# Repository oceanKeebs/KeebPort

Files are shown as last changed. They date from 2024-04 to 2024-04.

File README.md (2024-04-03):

# KeebPort

Keeb Port is a split keyboard architecture with a central part housing a micro controller and 6 keys (two keys can be replaced with encoders optionally). Right and left part of the split keyboard do not include a micro controller but an IO expander (MCP23017) processing the key activation information and connected via i2c to the central part. The LED control signal is generated by the micro controller and provided via a separate line to both split keyboard parts. Central and split keyboard parts are connected with TRRRS (5-pin). All layouts share the same firmware.

## QMK Firmware source files

### RP2040 QMK firmware source files

<https://github.com/oceanKeebs/qmk_firmware/tree/master/keyboards/oceankeebs/expanded_split_rp_tps43>

## QMK Firmware hex files

### RP2040 QMK firmware hex files

**without via support:**
<https://github.com/oceanKeebs/KeebPort/blob/main/HexFiles/oceankeebs_expanded_split_rp_tps43_default.uf2>

**with via support:**
<https://github.com/oceanKeebs/KeebPort/blob/main/HexFiles/oceankeebs_expanded_split_rp_tps43_via.uf2>

## Keeb Port RP2040

Central part for all split keyboard layouts housing a PGA2040, a TPS65 touch pad and 6 keys (two keys can be replaced with encoders optionally). Needed for all keyboard layouts of this repository.
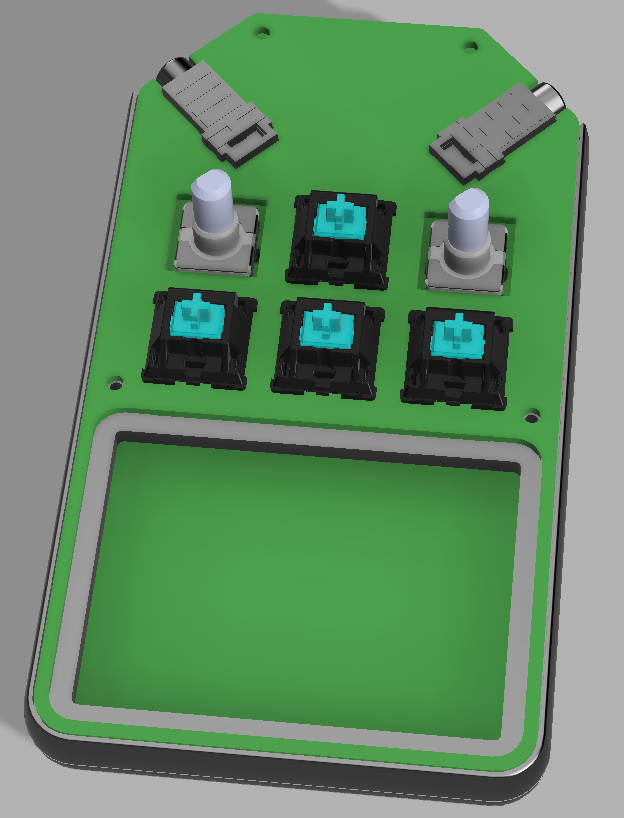
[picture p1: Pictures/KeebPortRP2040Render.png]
KeebPortRP2040Render


### PCBs

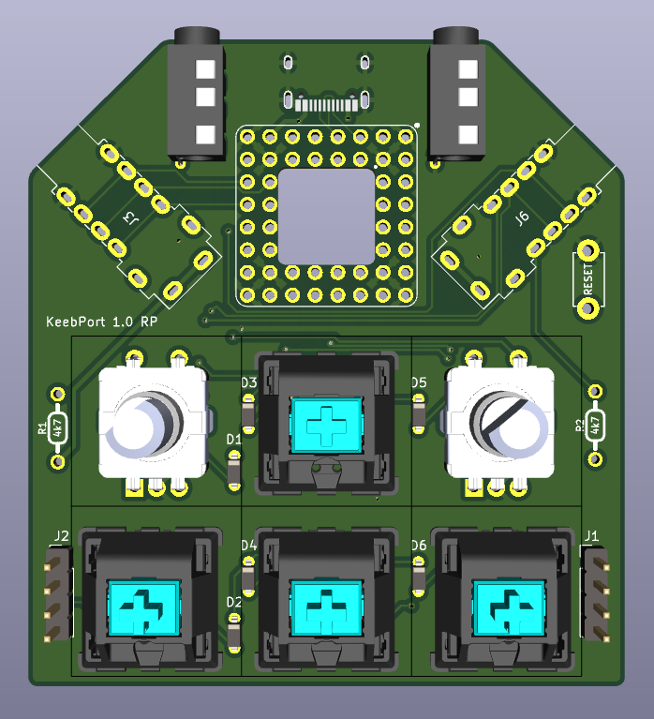
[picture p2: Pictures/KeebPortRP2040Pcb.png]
Keeb Port Pcb

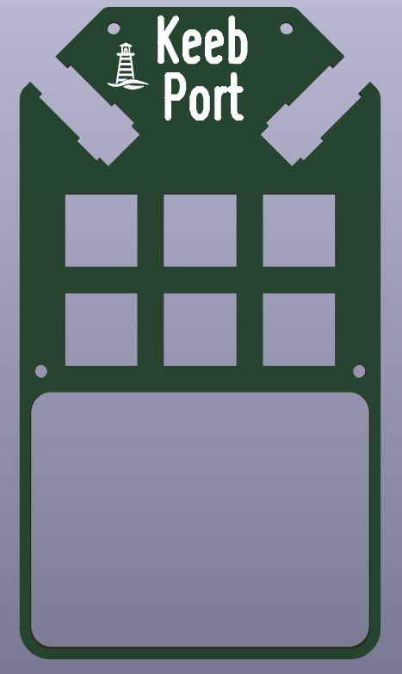
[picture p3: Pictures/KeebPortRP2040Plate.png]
Keeb Port Plate

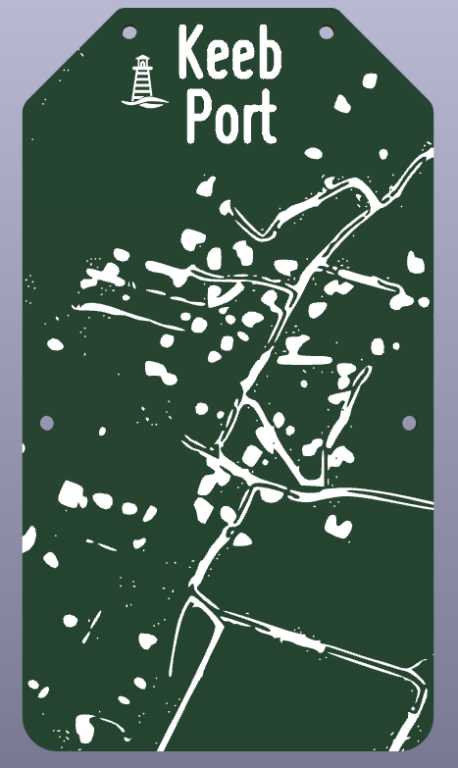
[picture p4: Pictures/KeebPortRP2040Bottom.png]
Keeb Port Bottom


### STLs

<https://github.com/oceanKeebs/KeebPort/StlFiles/KeebPort_RP2040>

## Kyrious Crab

A SplitKb Kyria inspired split keyboard layout with more aggressive stagger and added num row. Per side 31 keys are available.
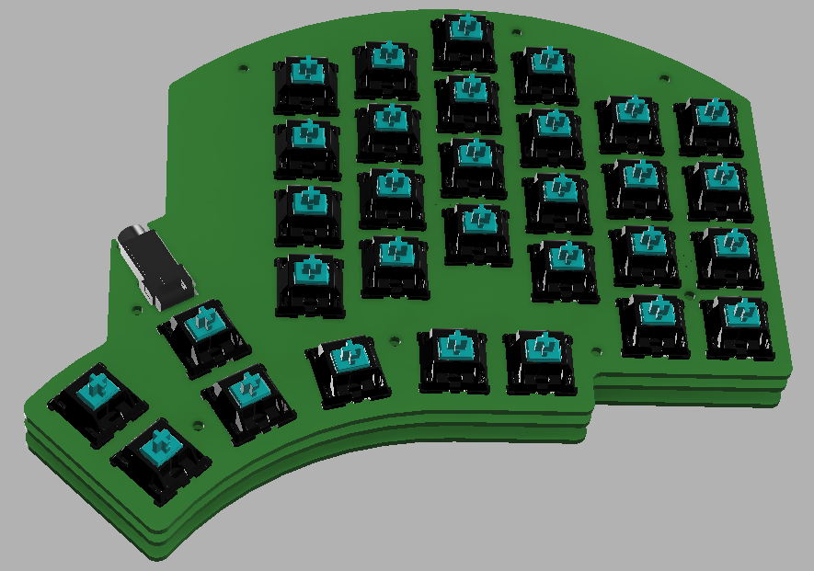
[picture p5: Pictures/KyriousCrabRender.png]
KyriousCrabRender


### PCBs

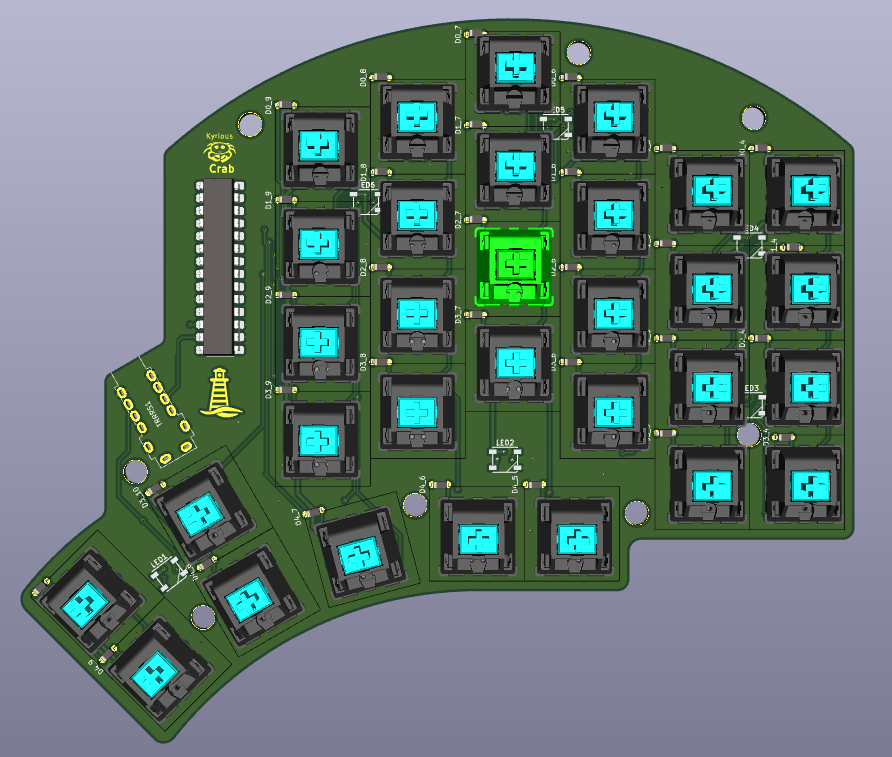
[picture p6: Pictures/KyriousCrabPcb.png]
Kyrious Crab Pcb

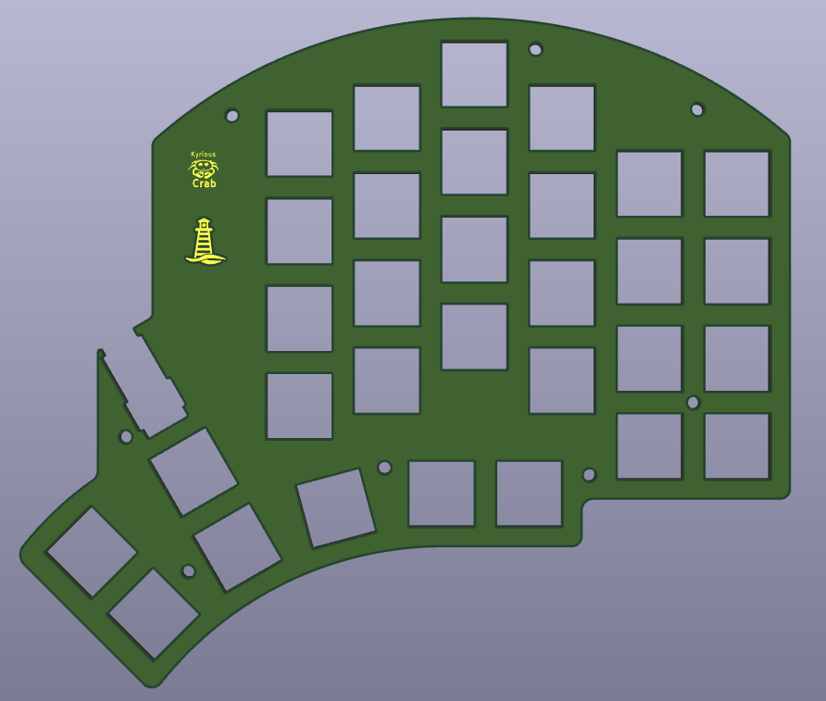
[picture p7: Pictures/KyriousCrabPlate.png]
Kyrious Crab Plate

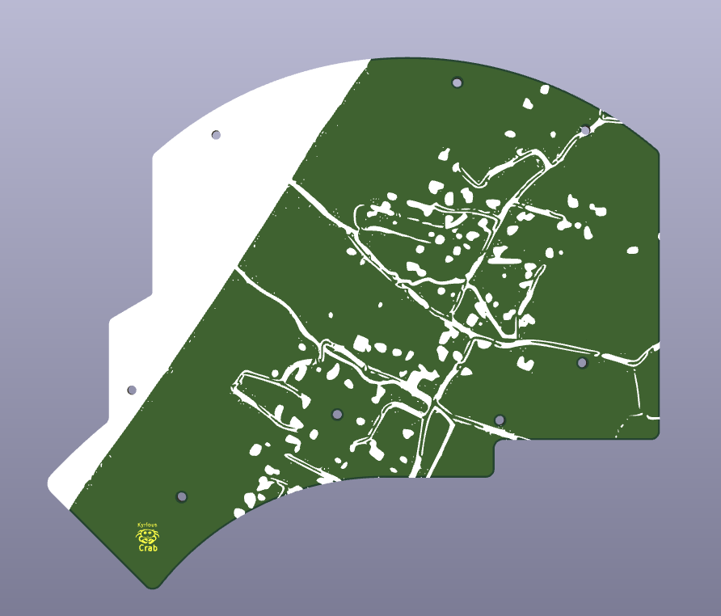
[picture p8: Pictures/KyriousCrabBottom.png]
Kyrious Crab Bottom


## Lucky Albatros

A Lily58 inspired split keyboard layout with 3 additional columns for arrow keys and/or macros. Per side 33 keys are available.
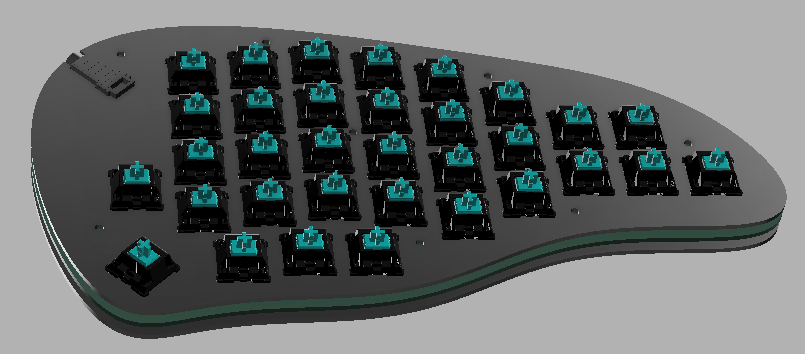
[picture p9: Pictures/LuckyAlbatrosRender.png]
LuckyAlbatrosRender


### PCBs

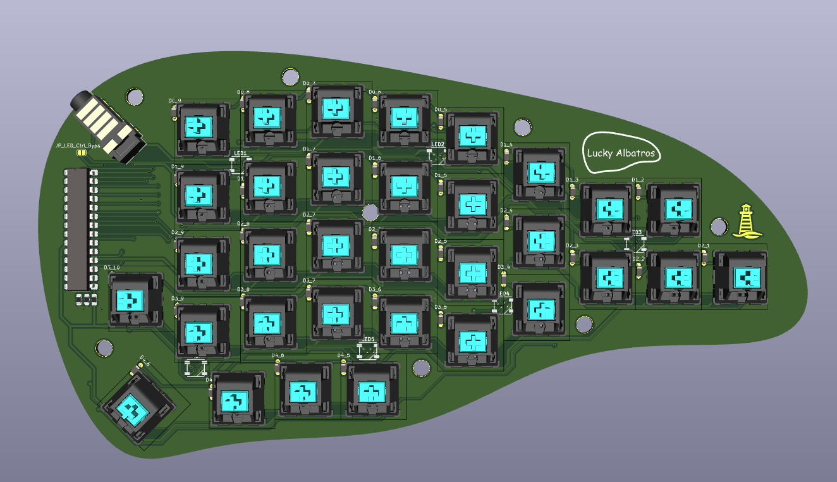
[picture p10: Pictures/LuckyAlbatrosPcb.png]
Lucky Albatros Pcb

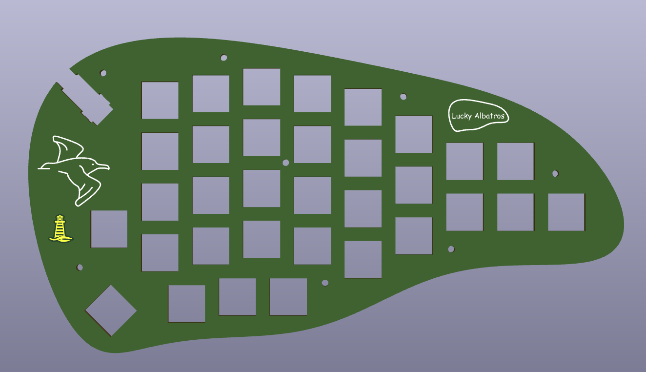
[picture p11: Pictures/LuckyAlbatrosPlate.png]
Lucky Albatros Plate

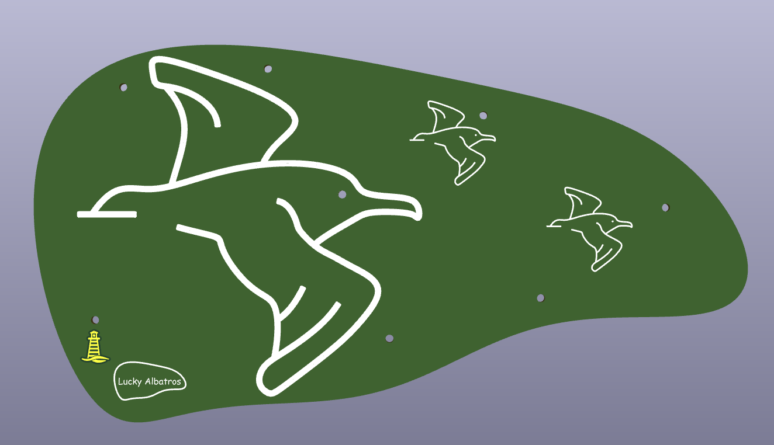
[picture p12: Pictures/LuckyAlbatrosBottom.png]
Lucky Albatros Bottom


## Template for Custom Layouts

The template can be used a starting point to design compatible custom layouts.

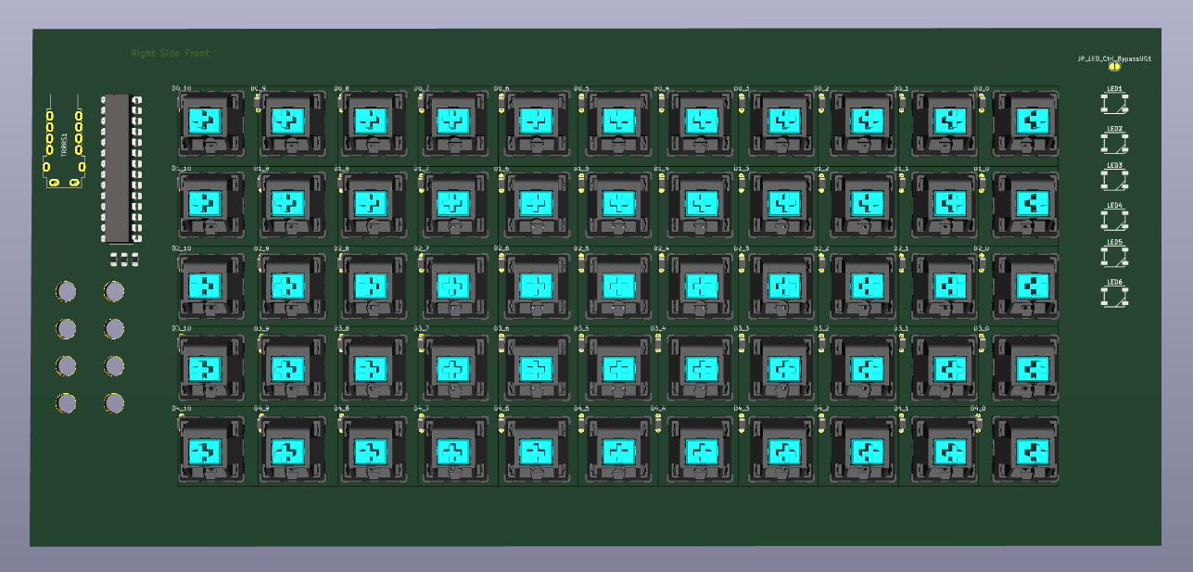
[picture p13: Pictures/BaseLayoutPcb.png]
Base Split Template


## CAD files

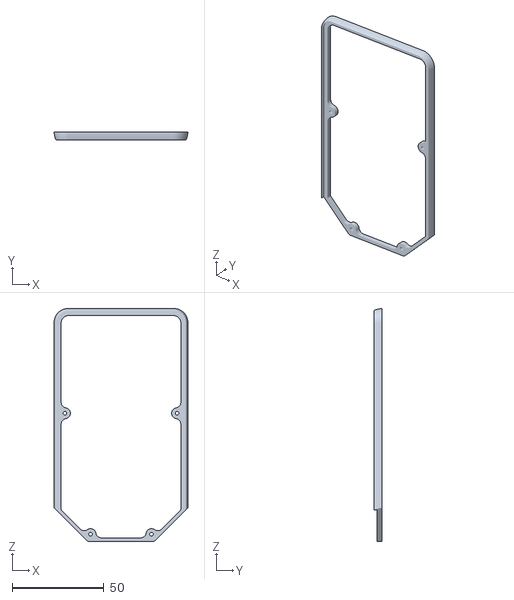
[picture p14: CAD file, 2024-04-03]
StlFiles/KeebPort_RP2040/Midplate_bottom.stl
73.0 x 4.20 x 127.0

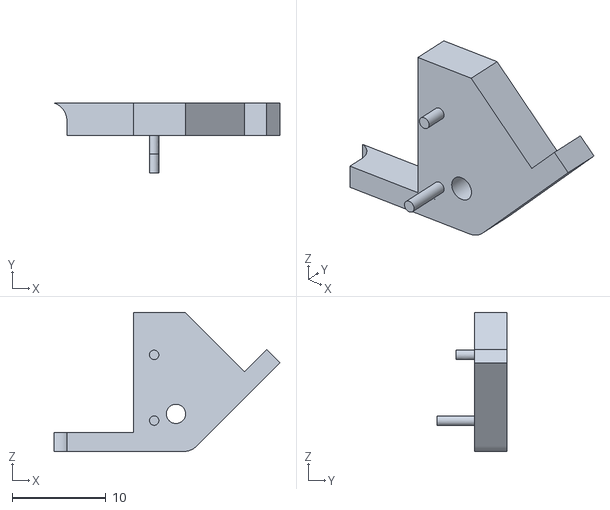
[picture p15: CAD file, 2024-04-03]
StlFiles/KeebPort_RP2040/Midplate_OR.stl
24.1 x 7.45 x 14.8

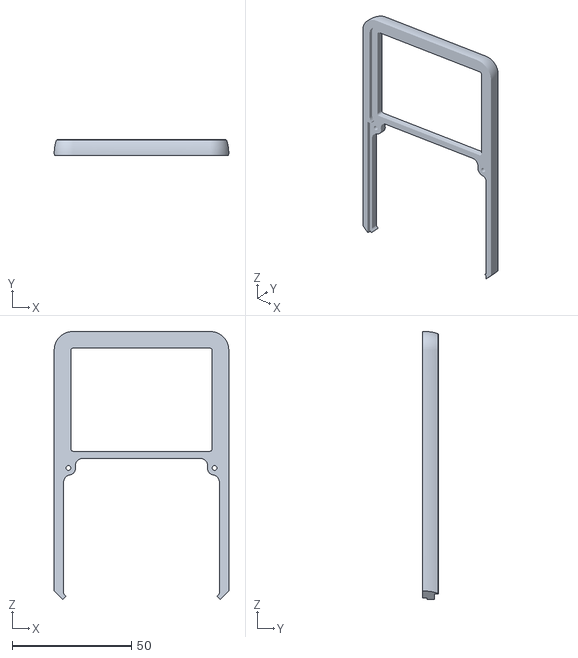
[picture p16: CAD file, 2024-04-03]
StlFiles/KeebPort_RP2040/Midplate_top.stl
73.1 x 6.60 x 112.2

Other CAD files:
StlFiles/KeebPort_RP2040/Midplate_OL.stl

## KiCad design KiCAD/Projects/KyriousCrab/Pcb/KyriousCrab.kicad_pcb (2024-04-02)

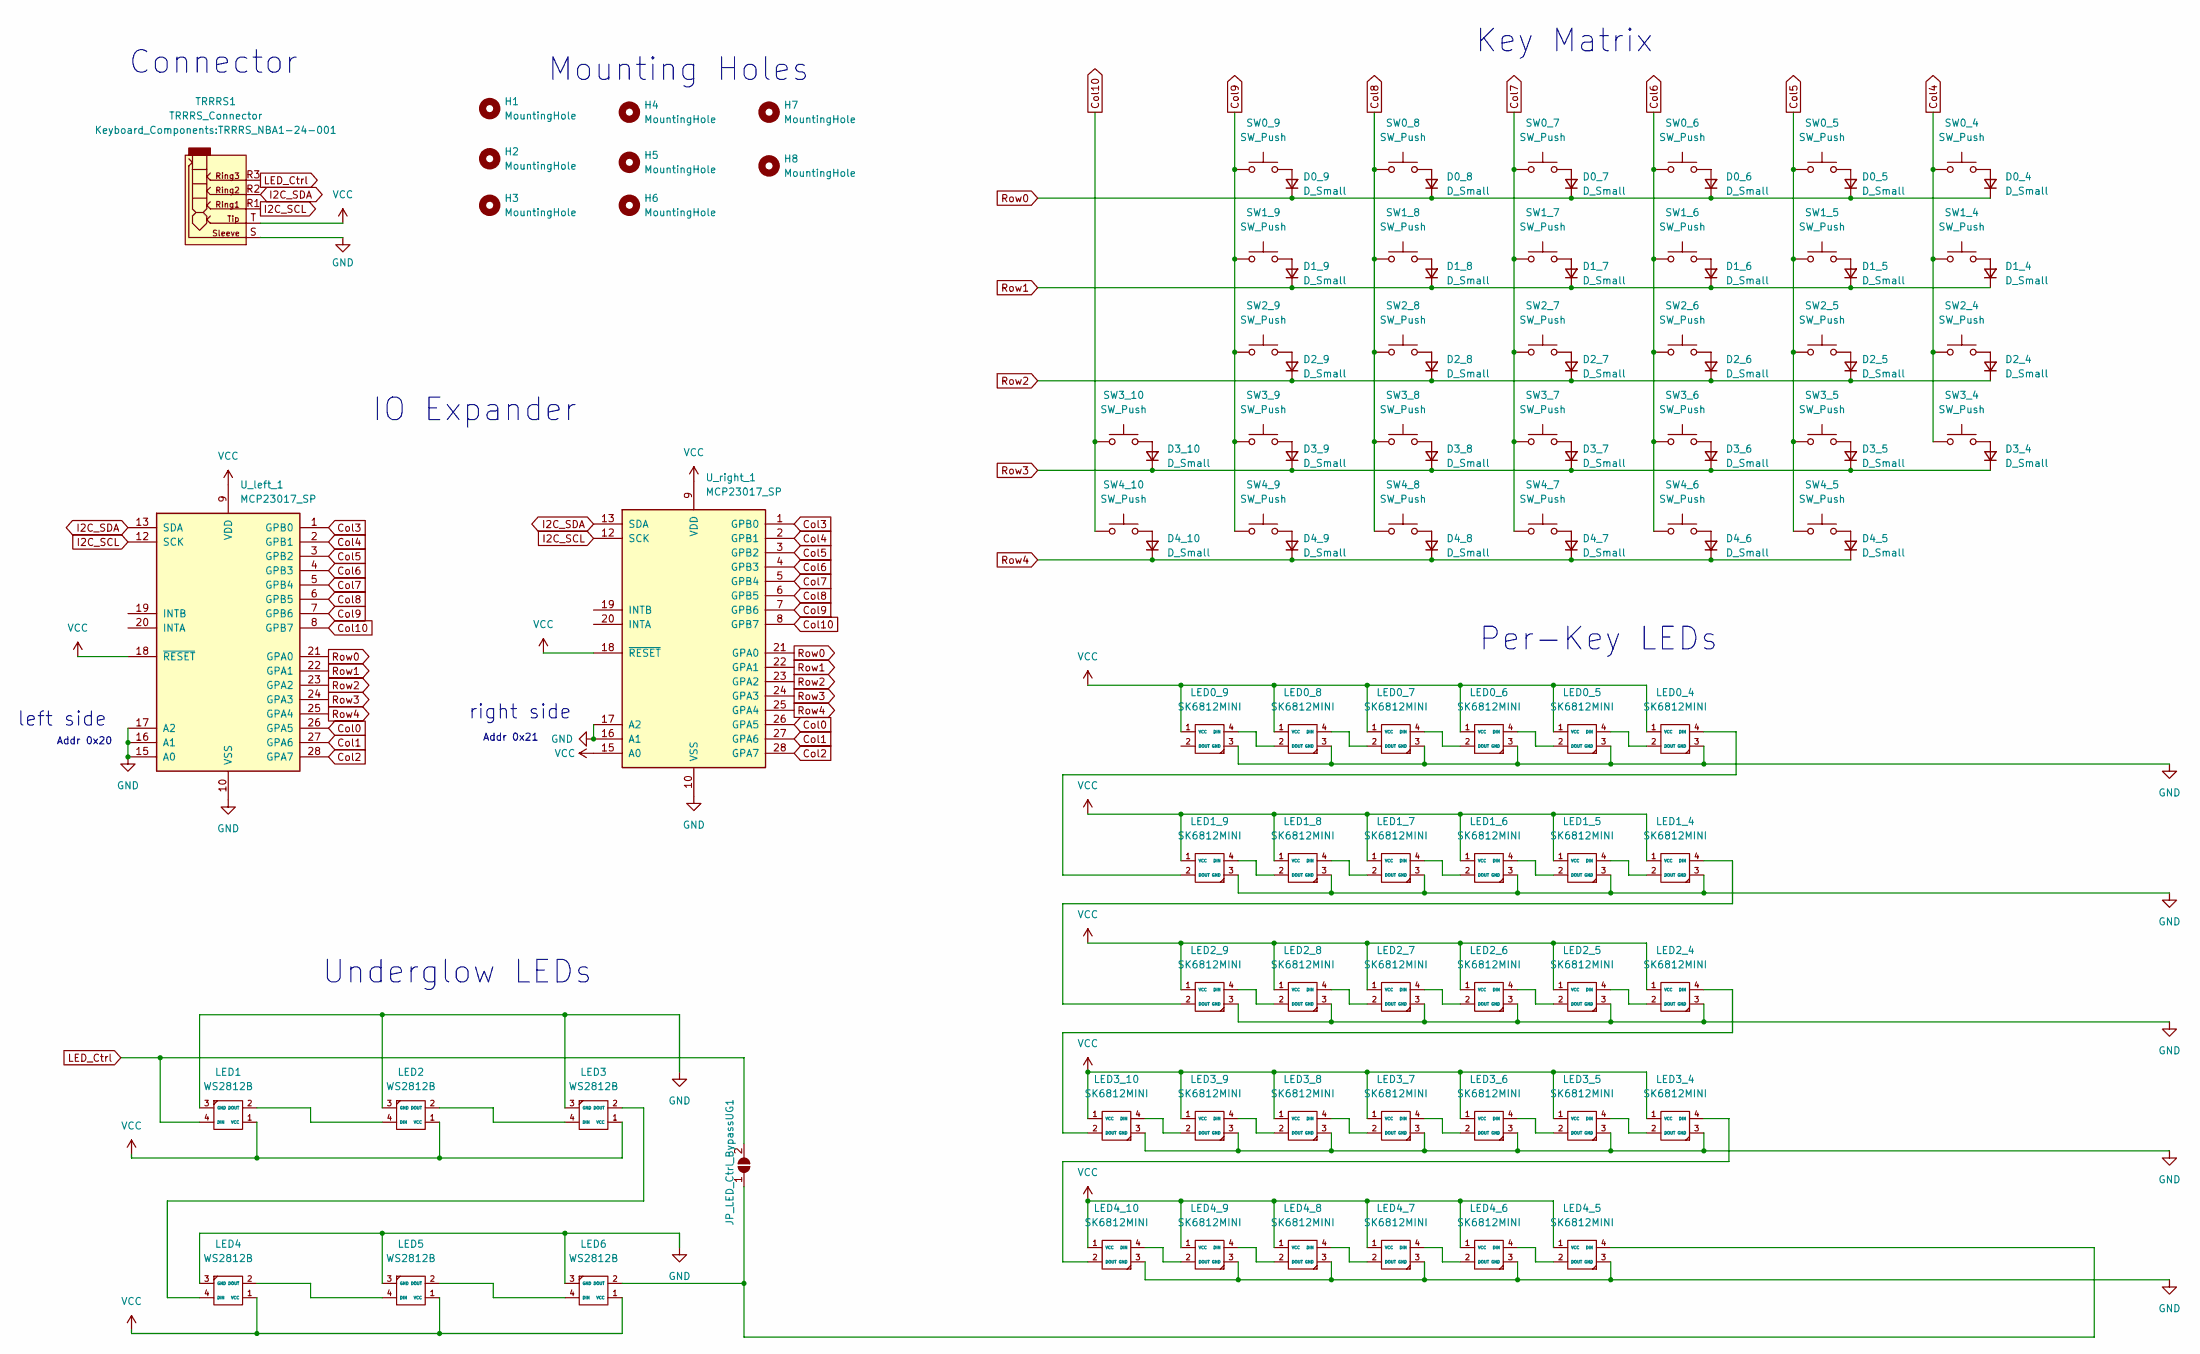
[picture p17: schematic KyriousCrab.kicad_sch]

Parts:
D0_4, D0_5, D0_6, D0_7, D0_8, D0_9, D1_4, D1_5, D1_6, D1_7, D1_8, D1_9, D2_4, D2_5, D2_6, D2_7, D2_8, D2_9, D3_4, D3_5, D3_6, D3_7, D3_8, D3_9, D3_10, D4_5, D4_6, D4_7, D4_8, D4_9, D4_10: D_Small; Diode_SMD_Round_Pads
H1, H2, H3, H4, H5, H6, H7, H8: MountingHole; Throughhole_Standoff
JP_LED_Ctrl_BypassUG1: SolderJumper_2_Open; SolderJumper-2_P1.3mm_Open_RoundedPad1.0x1.5mm
LED0_4, LED0_5, LED0_6, LED0_7, LED0_8, LED0_9, LED1_4, LED1_5, LED1_6, LED1_7, LED1_8, LED1_9, LED2_4, LED2_5, LED2_6, LED2_7, LED2_8, LED2_9, LED3_4, LED3_5, LED3_6, LED3_7, LED3_8, LED3_9, LED3_10, LED4_5, LED4_6, LED4_7, LED4_8, LED4_9, LED4_10: SK6812MINI; SK6812MiniE_MX_Addon
LED1, LED2, LED3, LED4, LED5, LED6: WS2812B; WS2812B_doublesided
SW0_4, SW0_5, SW0_6, SW0_7, SW0_8, SW0_9, SW1_4, SW1_5, SW1_6, SW1_7, SW1_8, SW1_9, SW2_4, SW2_5, SW2_6, SW2_7, SW2_8, SW2_9, SW3_4, SW3_5, SW3_6, SW3_7, SW3_8, SW3_9, SW3_10, SW4_5, SW4_6, SW4_7, SW4_8, SW4_9, SW4_10: SW_Push; MX_lss_100U_doubleSided
TRRRS1: TRRRS_Connector; TRRRS_NBA1-24-001
U_left_1: MCP23017_SP; MCP23017_THTasSMD_Singlesided
U_right_1: MCP23017_SP; MCP23017_THTasSMD_Singlesided

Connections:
Col0: U_left_1.26 (GPA5), U_right_1.26 (GPA5)
Col1: U_left_1.27 (GPA6), U_right_1.27 (GPA6)
Col2: U_left_1.28 (GPA7), U_right_1.28 (GPA7)
Col3: U_left_1.1 (GPB0), U_right_1.1 (GPB0)
Col4: SW0_4.1, SW1_4.1, SW2_4.1, SW3_4.1, U_left_1.2 (GPB1), U_right_1.2 (GPB1)
Col5: SW0_5.1, SW1_5.1, SW2_5.1, SW3_5.1, SW4_5.1, U_left_1.3 (GPB2), U_right_1.3 (GPB2)
Col6: SW0_6.1, SW1_6.1, SW2_6.1, SW3_6.1, SW4_6.1, U_left_1.4 (GPB3), U_right_1.4 (GPB3)
Col7: SW0_7.1, SW1_7.1, SW2_7.1, SW3_7.1, SW4_7.1, U_left_1.5 (GPB4), U_right_1.5 (GPB4)
Col8: SW0_8.1, SW1_8.1, SW2_8.1, SW3_8.1, SW4_8.1, U_left_1.6 (GPB5), U_right_1.6 (GPB5)
Col9: SW0_9.1, SW1_9.1, SW2_9.1, SW3_9.1, SW4_9.1, U_left_1.7 (GPB6), U_right_1.7 (GPB6)
Col10: SW3_10.1, SW4_10.1, U_left_1.8 (GPB7), U_right_1.8 (GPB7)
GND: LED0_4.3 (GND), LED0_5.3 (GND), LED0_6.3 (GND), LED0_7.3 (GND), LED0_8.3 (GND), LED0_9.3 (GND), LED1.3 (GND), LED1_4.3 (GND), LED1_5.3 (GND), LED1_6.3 (GND), LED1_7.3 (GND), LED1_8.3 (GND), LED1_9.3 (GND), LED2.3 (GND), LED2_4.3 (GND), LED2_5.3 (GND), LED2_6.3 (GND), LED2_7.3 (GND), LED2_8.3 (GND), LED2_9.3 (GND), LED3.3 (GND), LED3_4.3 (GND), LED3_5.3 (GND), LED3_6.3 (GND), LED3_7.3 (GND), LED3_8.3 (GND), LED3_9.3 (GND), LED3_10.3 (GND), LED4.3 (GND), LED4_5.3 (GND), LED4_6.3 (GND), LED4_7.3 (GND), LED4_8.3 (GND), LED4_9.3 (GND), LED4_10.3 (GND), LED5.3 (GND), LED6.3 (GND), TRRRS1.S, U_left_1.10 (VSS), U_left_1.15 (A0), U_left_1.16 (A1), U_left_1.17 (A2), U_right_1.10 (VSS), U_right_1.16 (A1), U_right_1.17 (A2)
I2C_SCL: TRRRS1.R1, U_left_1.12 (SCK), U_right_1.12 (SCK)
I2C_SDA: TRRRS1.R2, U_left_1.13 (SDA), U_right_1.13 (SDA)
LED_Ctrl: JP_LED_Ctrl_BypassUG1.2 (B), LED1.4 (DIN), TRRRS1.R3
unnamed: D0_4.2 (A), SW0_4.2
unnamed: D0_5.2 (A), SW0_5.2
unnamed: D0_6.2 (A), SW0_6.2
unnamed: D0_7.2 (A), SW0_7.2
unnamed: D0_8.2 (A), SW0_8.2
unnamed: D0_9.2 (A), SW0_9.2
unnamed: D1_4.2 (A), SW1_4.2
unnamed: D1_5.2 (A), SW1_5.2
unnamed: D1_6.2 (A), SW1_6.2
unnamed: D1_7.2 (A), SW1_7.2
unnamed: D1_8.2 (A), SW1_8.2
unnamed: D1_9.2 (A), SW1_9.2
unnamed: D2_4.2 (A), SW2_4.2
unnamed: D2_5.2 (A), SW2_5.2
unnamed: D2_6.2 (A), SW2_6.2
unnamed: D2_7.2 (A), SW2_7.2
unnamed: D2_8.2 (A), SW2_8.2
unnamed: D2_9.2 (A), SW2_9.2
unnamed: D3_4.2 (A), SW3_4.2
unnamed: D3_5.2 (A), SW3_5.2
unnamed: D3_6.2 (A), SW3_6.2
unnamed: D3_7.2 (A), SW3_7.2
unnamed: D3_8.2 (A), SW3_8.2
unnamed: D3_9.2 (A), SW3_9.2
unnamed: D3_10.2 (A), SW3_10.2
unnamed: D4_5.2 (A), SW4_5.2
unnamed: D4_6.2 (A), SW4_6.2
unnamed: D4_7.2 (A), SW4_7.2
unnamed: D4_8.2 (A), SW4_8.2
unnamed: D4_9.2 (A), SW4_9.2
unnamed: D4_10.2 (A), SW4_10.2
unnamed: JP_LED_Ctrl_BypassUG1.1 (A), LED4_5.4 (DIN), LED6.2 (DOUT)
unnamed: LED0_4.2 (DOUT), LED0_5.4 (DIN)
unnamed: LED0_4.4 (DIN), LED1_9.2 (DOUT)
unnamed: LED0_5.2 (DOUT), LED0_6.4 (DIN)
unnamed: LED0_6.2 (DOUT), LED0_7.4 (DIN)
unnamed: LED0_7.2 (DOUT), LED0_8.4 (DIN)
unnamed: LED0_8.2 (DOUT), LED0_9.4 (DIN)
unnamed: LED1.2 (DOUT), LED2.4 (DIN)
unnamed: LED1_4.2 (DOUT), LED1_5.4 (DIN)
unnamed: LED1_4.4 (DIN), LED2_9.2 (DOUT)
unnamed: LED1_5.2 (DOUT), LED1_6.4 (DIN)
unnamed: LED1_6.2 (DOUT), LED1_7.4 (DIN)
unnamed: LED1_7.2 (DOUT), LED1_8.4 (DIN)
unnamed: LED1_8.2 (DOUT), LED1_9.4 (DIN)
unnamed: LED2.2 (DOUT), LED3.4 (DIN)
unnamed: LED2_4.2 (DOUT), LED2_5.4 (DIN)
unnamed: LED2_4.4 (DIN), LED3_10.2 (DOUT)
unnamed: LED2_5.2 (DOUT), LED2_6.4 (DIN)
unnamed: LED2_6.2 (DOUT), LED2_7.4 (DIN)
unnamed: LED2_7.2 (DOUT), LED2_8.4 (DIN)
unnamed: LED2_8.2 (DOUT), LED2_9.4 (DIN)
unnamed: LED3.2 (DOUT), LED4.4 (DIN)
unnamed: LED3_4.2 (DOUT), LED3_5.4 (DIN)
unnamed: LED3_4.4 (DIN), LED4_10.2 (DOUT)
unnamed: LED3_5.2 (DOUT), LED3_6.4 (DIN)
unnamed: LED3_6.2 (DOUT), LED3_7.4 (DIN)
unnamed: LED3_7.2 (DOUT), LED3_8.4 (DIN)
unnamed: LED3_8.2 (DOUT), LED3_9.4 (DIN)
unnamed: LED3_9.2 (DOUT), LED3_10.4 (DIN)
unnamed: LED4.2 (DOUT), LED5.4 (DIN)
unnamed: LED4_5.2 (DOUT), LED4_6.4 (DIN)
unnamed: LED4_6.2 (DOUT), LED4_7.4 (DIN)
unnamed: LED4_7.2 (DOUT), LED4_8.4 (DIN)
unnamed: LED4_8.2 (DOUT), LED4_9.4 (DIN)
unnamed: LED4_9.2 (DOUT), LED4_10.4 (DIN)
unnamed: LED5.2 (DOUT), LED6.4 (DIN)
Row0: D0_4.1 (K), D0_5.1 (K), D0_6.1 (K), D0_7.1 (K), D0_8.1 (K), D0_9.1 (K), U_left_1.21 (GPA0), U_right_1.21 (GPA0)
Row1: D1_4.1 (K), D1_5.1 (K), D1_6.1 (K), D1_7.1 (K), D1_8.1 (K), D1_9.1 (K), U_left_1.22 (GPA1), U_right_1.22 (GPA1)
Row2: D2_4.1 (K), D2_5.1 (K), D2_6.1 (K), D2_7.1 (K), D2_8.1 (K), D2_9.1 (K), U_left_1.23 (GPA2), U_right_1.23 (GPA2)
Row3: D3_4.1 (K), D3_5.1 (K), D3_6.1 (K), D3_7.1 (K), D3_8.1 (K), D3_9.1 (K), D3_10.1 (K), U_left_1.24 (GPA3), U_right_1.24 (GPA3)
Row4: D4_5.1 (K), D4_6.1 (K), D4_7.1 (K), D4_8.1 (K), D4_9.1 (K), D4_10.1 (K), U_left_1.25 (GPA4), U_right_1.25 (GPA4)
VCC: LED0_4.1 (VCC), LED0_5.1 (VCC), LED0_6.1 (VCC), LED0_7.1 (VCC), LED0_8.1 (VCC), LED0_9.1 (VCC), LED1.1 (VCC), LED1_4.1 (VCC), LED1_5.1 (VCC), LED1_6.1 (VCC), LED1_7.1 (VCC), LED1_8.1 (VCC), LED1_9.1 (VCC), LED2.1 (VCC), LED2_4.1 (VCC), LED2_5.1 (VCC), LED2_6.1 (VCC), LED2_7.1 (VCC), LED2_8.1 (VCC), LED2_9.1 (VCC), LED3.1 (VCC), LED3_4.1 (VCC), LED3_5.1 (VCC), LED3_6.1 (VCC), LED3_7.1 (VCC), LED3_8.1 (VCC), LED3_9.1 (VCC), LED3_10.1 (VCC), LED4.1 (VCC), LED4_5.1 (VCC), LED4_6.1 (VCC), LED4_7.1 (VCC), LED4_8.1 (VCC), LED4_9.1 (VCC), LED4_10.1 (VCC), LED5.1 (VCC), LED6.1 (VCC), TRRRS1.T, U_left_1.9 (VDD), U_left_1.18 (~RESET), U_right_1.9 (VDD), U_right_1.15 (A0), U_right_1.18 (~RESET)

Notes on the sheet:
IO Expander
Mounting Holes
Underglow LEDs
Connector
Addr 0x21
right side
left side
Key Matrix
Per-Key LEDs
Addr 0x20

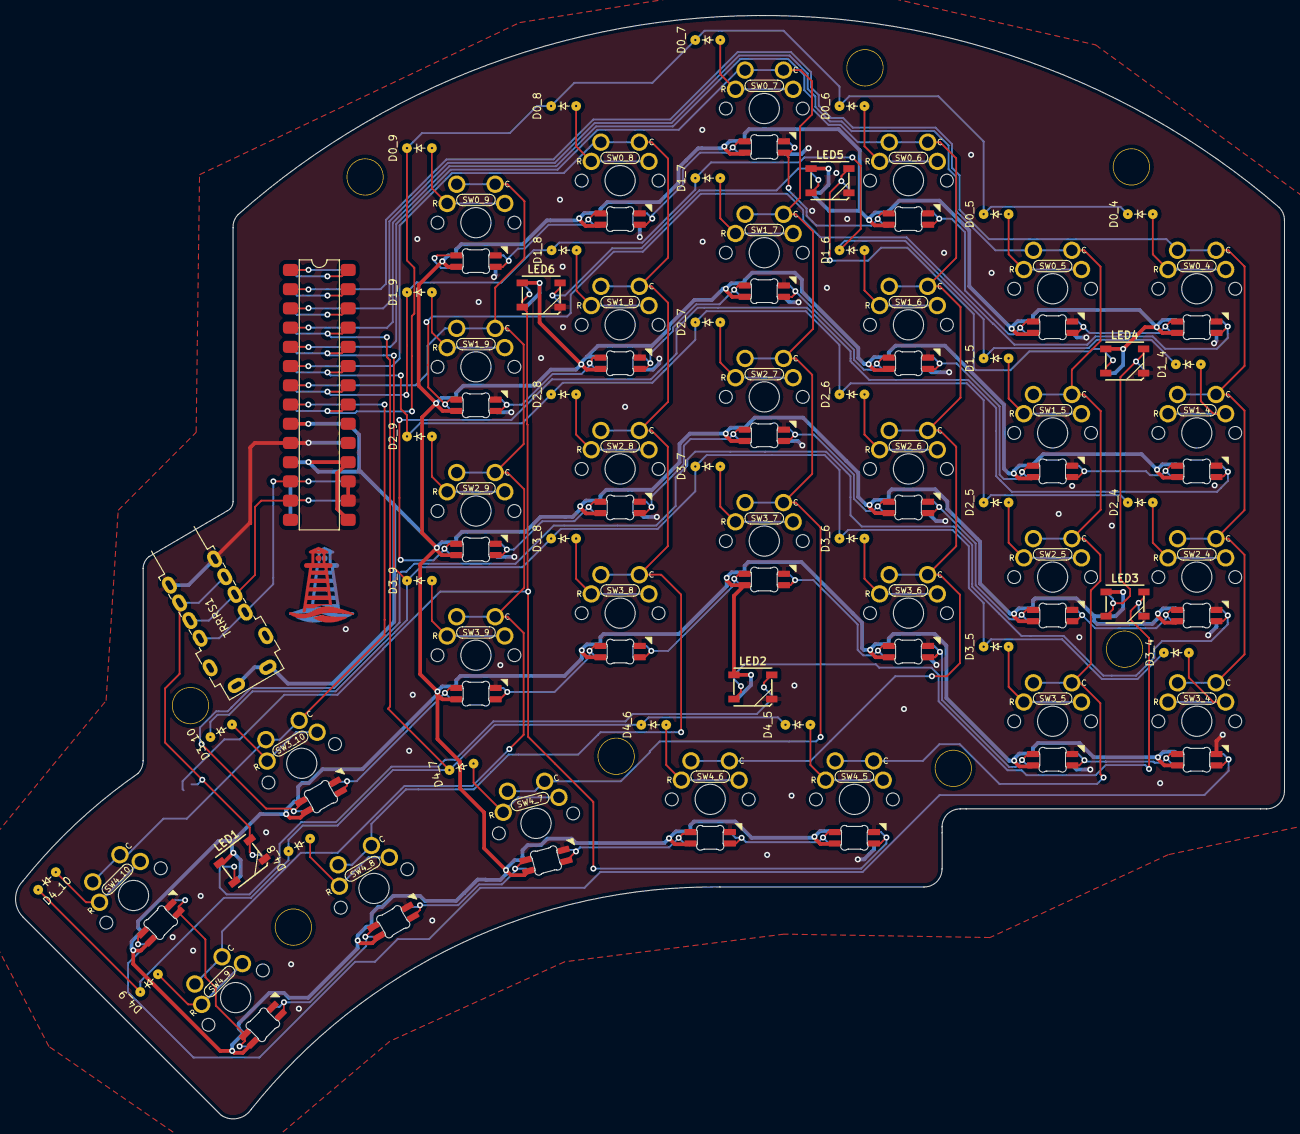
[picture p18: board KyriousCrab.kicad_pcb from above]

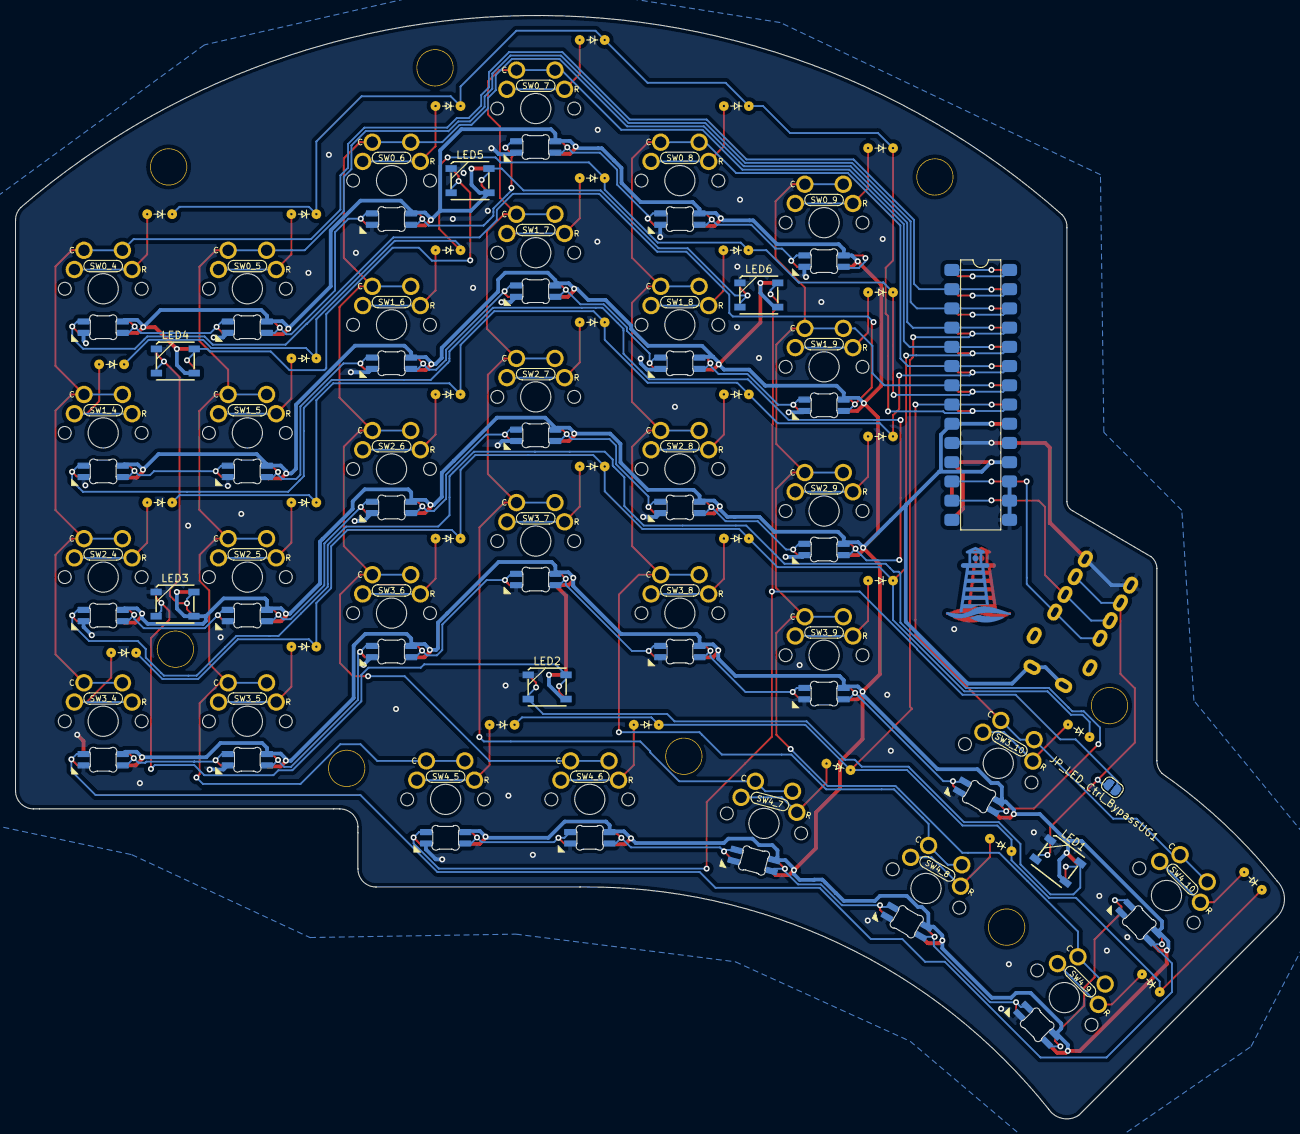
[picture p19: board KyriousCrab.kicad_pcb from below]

Board: 2 copper layers, 167.7 x 145.8 mm, 112 parts (2 on the bottom side), 88 nets.

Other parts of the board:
Ref**: Val**; Leuchtturm_10x10

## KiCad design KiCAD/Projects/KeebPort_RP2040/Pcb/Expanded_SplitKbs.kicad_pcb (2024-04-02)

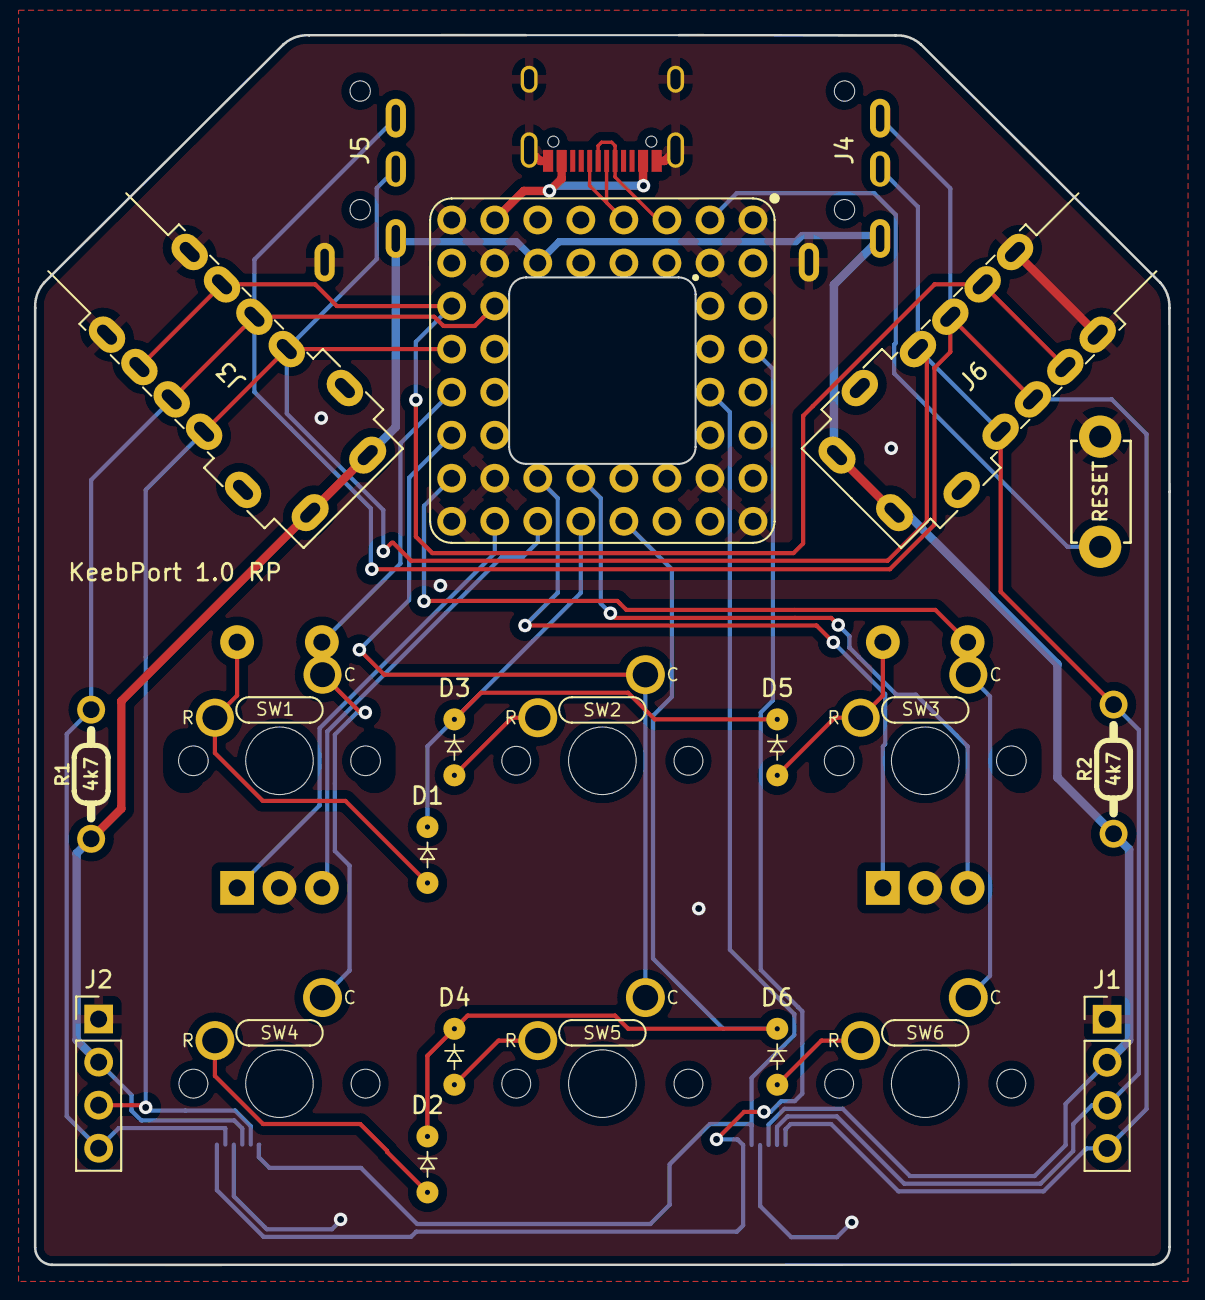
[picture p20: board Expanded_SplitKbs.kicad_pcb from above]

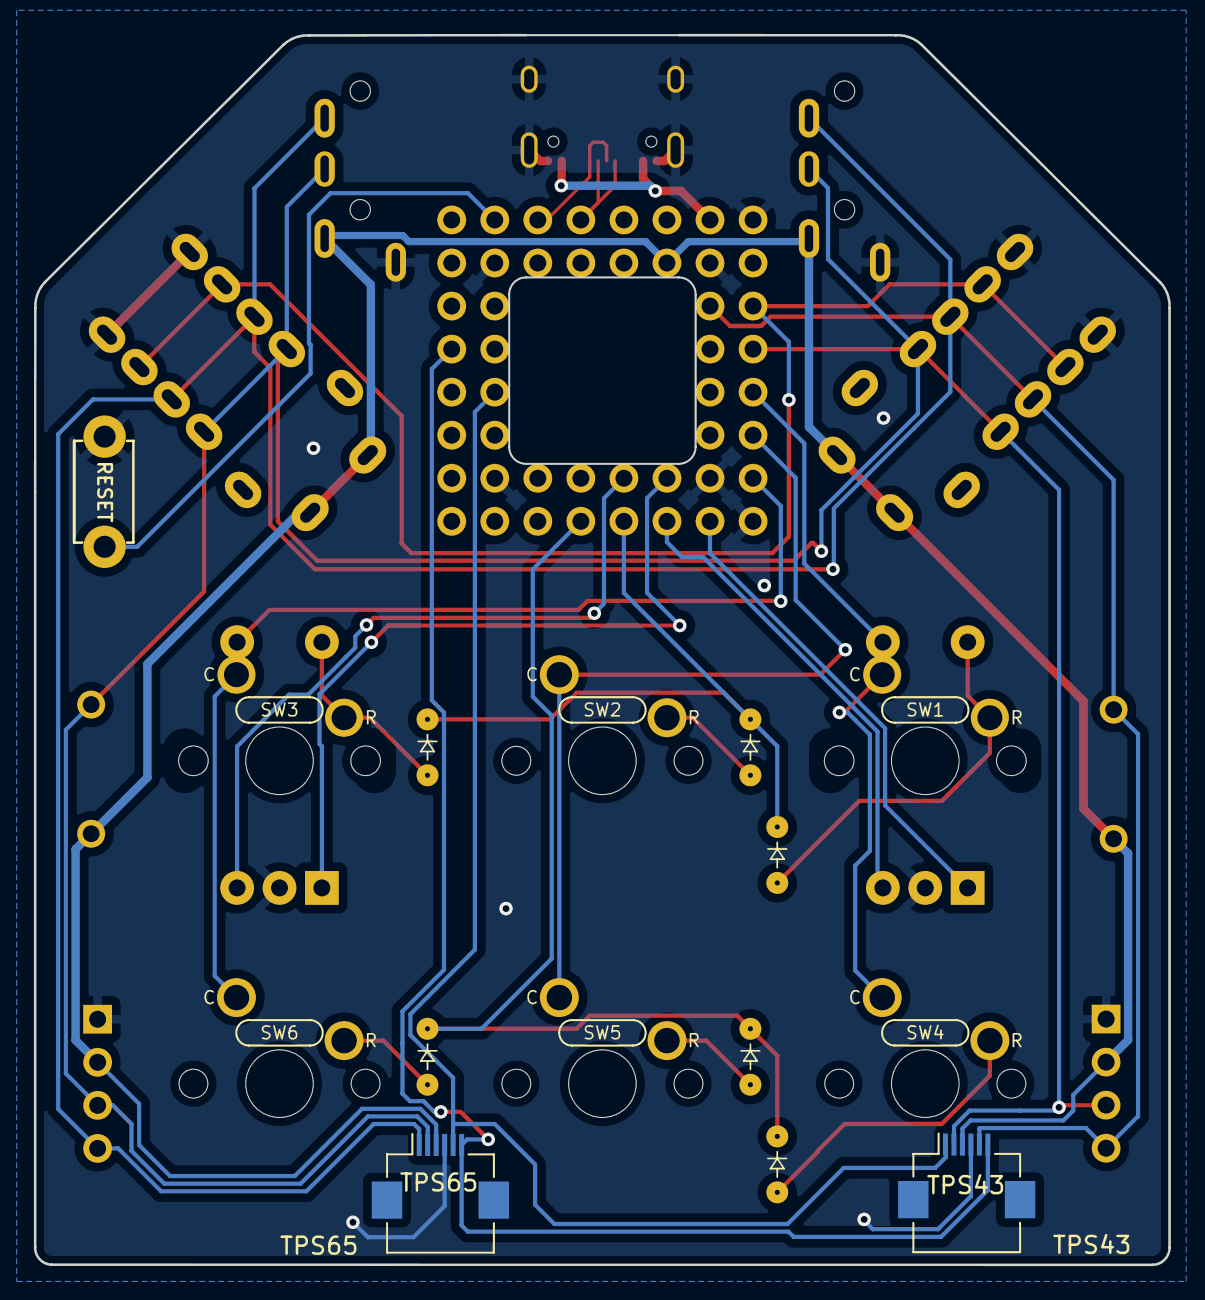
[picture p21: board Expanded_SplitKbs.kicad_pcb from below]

Board: 2 copper layers, 66.9 x 72.5 mm, 25 parts (2 on the bottom side), 26 nets.

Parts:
D1, D2, D3, D4, D5, D6: D_Small; Diode_SMD_Round_Pads
J1, J2: Conn_01x04_Female; PinHeader_1x04_P2.54mm_Vertical
J3, J6: TRRRS_Connector; TRRRS_NBA1-24-001
J4, J5: TRRS_Connector; TRRS_PJ-320A
P1: USB_C_Plug; USB_C_C2927037
R1, R2: 4k7; Resistor
SW1, SW3: RotaryEncoder_Switch; MX_lss_100U_Rotary
SW2, SW4, SW5, SW6: SW_Push; MX_lss_100U
SW7: SW_Push; Reset_Switch
TPS43, TPS65: Conn_01x06_Shielded; Hirose_FH12-6S-0.5SH_1x06-1MP_P0.50mm_Horizontal
U1: PGA2040

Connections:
+3V3: J1.2, J2.2, J3.T, J4.T, J5.T, J6.T, R1.1, R2.1, TPS43.3, TPS65.3, U1.B3 (3V3)
Col0: SW1.S2, SW4.1, U1.E1 (GPIO5)
Col1: SW2.1, SW5.1, U1.F1 (GPIO7)
Col2: SW3.S2, SW6.1, U1.G1 (GPIO9)
Enc0_A: SW1.A, U1.H2 (GPIO10)
Enc0_B: SW1.B, U1.H3 (GPIO11)
Enc1_A: SW3.A, U1.G3 (GPIO12)
Enc1_B: SW3.B, U1.G4 (GPIO14)
GND: J1.1, J2.1, J3.S, J4.S, J5.S, J6.S, P1.A1 (GND), P1.A12 (GND), P1.S1 (SHIELD), SW1.C, SW3.C, SW7.1, TPS43.4, TPS65.4, U1.A1 (GND), U1.A8 (GND), U1.B2 (GND), U1.B7 (GND), U1.G2 (GND), U1.G7 (GND), U1.H1 (GND), U1.H8 (GND)
I2C_SCL: J1.3, J2.3, J3.R1, J4.R1, J5.R1, J6.R1, R2.2, TPS43.2, TPS65.2, U1.D1 (GPIO3)
I2C_SDA: J1.4, J2.4, J3.R2, J4.R2, J5.R2, J6.R2, R1.2, TPS43.5, TPS65.1, U1.C2 (GPIO2)
LED_Ctrl: J3.R3, J6.R3, U1.C1 (GPIO1)
NRST: TPS43.1, TPS65.5, U1.E7 (GPIO24)
unnamed: D1.2 (A), SW1.S1
unnamed: D2.2 (A), SW4.2
unnamed: D3.2 (A), SW2.2
unnamed: D4.2 (A), SW5.2
unnamed: D5.2 (A), SW3.S1
unnamed: D6.2 (A), SW6.2
unnamed: SW7.2, U1.A7 (BOOTSEL)
RDY: TPS43.6, TPS65.6, U1.D8 (GPIO25)
Row0: D1.1 (K), D3.1 (K), D5.1 (K), U1.H4 (GPIO13)
Row1: D2.1 (K), D4.1 (K), D6.1 (K), U1.H5 (GPIO15)
USB_D+: P1.A6 (D+), P1.B6 (D+), U1.A5 (USB_DP)
USB_D-: P1.A7 (D-), P1.B7 (D-), U1.A6 (USB_DM)
VBUS: P1.A4 (VBUS), P1.A9 (VBUS), U1.A2 (VBUS)

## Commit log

2024-04-02 Added KiCAD info, pictures and hex files
    [ExpandedSplit_Center_PGA2040_Bottom.kicad_pcb, ExpandedSplit_Center_PGA2040_Bottom.kicad_sch, ExpandedSplit_Center_PGA2040_Plate.kicad_pcb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]
2024-04-03 Added render and stl files
    [Midplate_OL.stl, Midplate_OR.stl, Midplate_bottom.stl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]
